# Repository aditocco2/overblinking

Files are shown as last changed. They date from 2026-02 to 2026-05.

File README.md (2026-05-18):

# Overblinking: The LED Matrix Graduation Cap

_lightslop taken to its logical extreme_

A DIY graduation cap project that shows a slideshow of pictures, GIFs, videos, and scrolling text messages on a 64x64 LED matrix.

Includes a high-performance LED matrix driver, a custom 3D printed mounting system, and a custom PCB.

thumb
staticmodetopdown
modesw

## Features
- Easy loading of data onto the SD card - no manual downscaling or image dumping needed
- SD card is exposed underneath the cap with a custom PCB, allowing easy replacement of cards
- Mode switch allows you to automatically switch to a less distracting "static mode" during speeches
- Whole system is powered through one battery pack
- Optional rain resistance using an acrylic sheet and 3D printed waterproofing shield
- Automatically initializes/recovers SD cards and survives card swaps
- Only required electronics skill for assembly is through-hole soldering
- Non-destructive design allows you to re-use components for other things post-ceremony (unlike the cap and gown themselves!)

## Build Your Own
For instructions on how to make your own LED matrix graduation cap, read the full guide [here](https://overblinking.substack.com)!

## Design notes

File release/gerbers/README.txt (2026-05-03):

Use control_board_2 if you have the Adafruit micro SD card breakout board.

Use control_board_2b if you could not get the Adafruit one and instead have the SparkFun one.

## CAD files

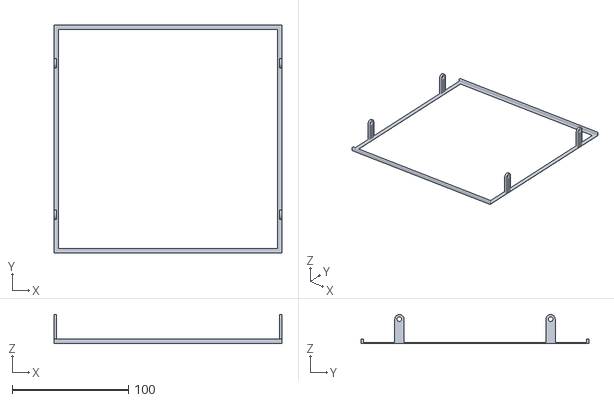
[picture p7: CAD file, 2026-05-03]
models/waterproofing_shield_2.stl
196.0 x 196.0 x 25.0

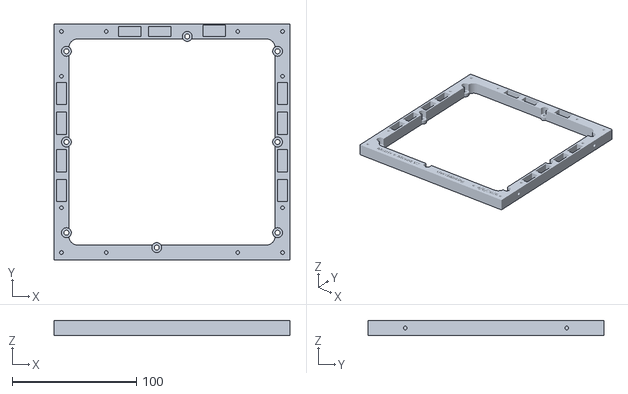
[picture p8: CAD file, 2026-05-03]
models/matrix_mount_2.stl
190.0 x 190.0 x 12.0

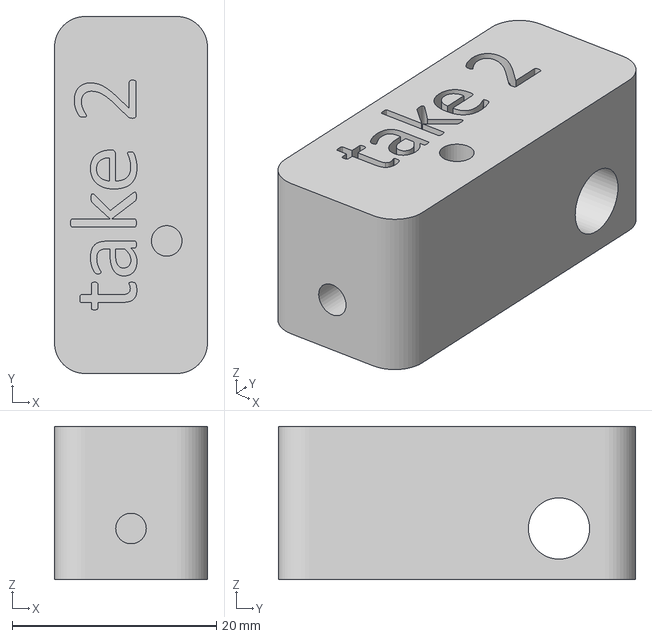
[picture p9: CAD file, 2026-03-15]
models/threadless_cube.3mf
15.0 x 35.0 x 15.0 mm

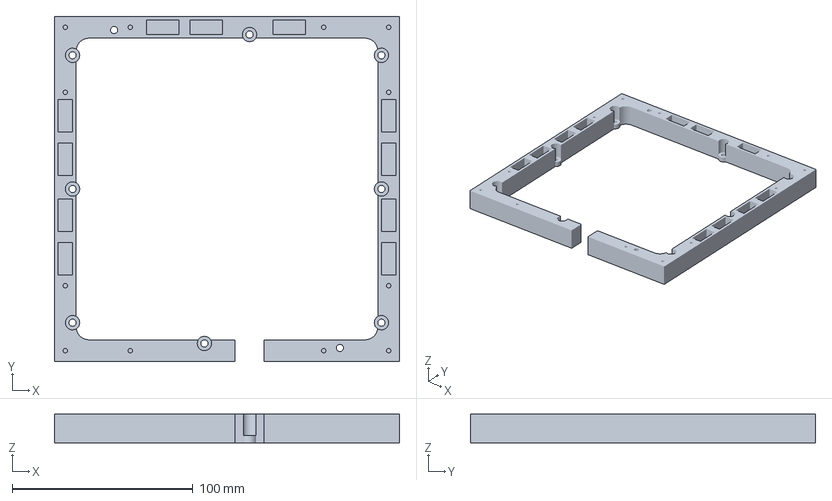
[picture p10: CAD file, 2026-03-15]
models/matrix_mount_1.3mf
191.0 x 191.0 x 16.0 mm

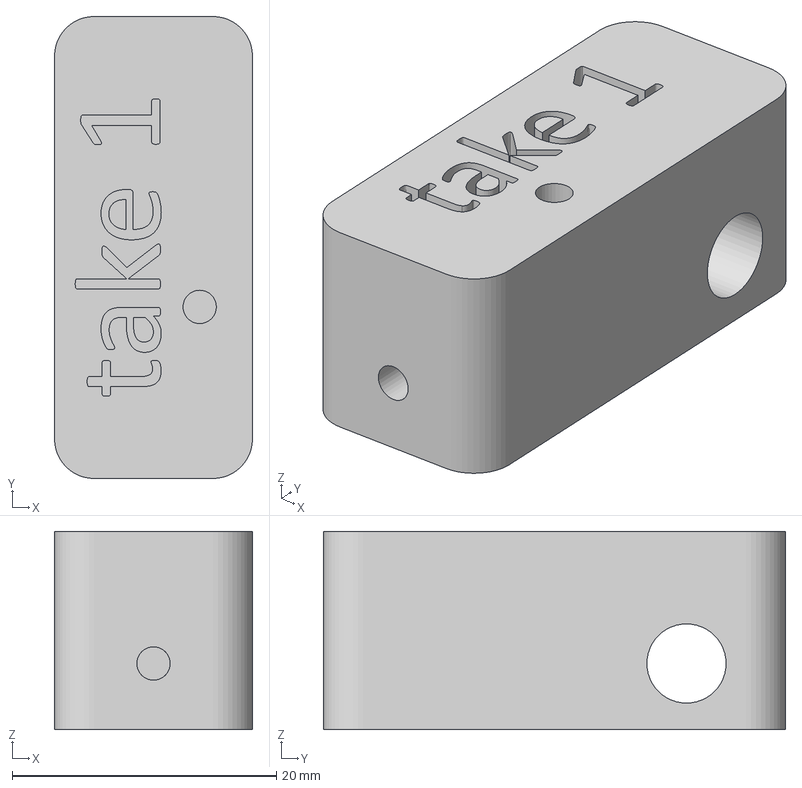
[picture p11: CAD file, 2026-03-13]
models/thread_cube.3mf
15.0 x 35.0 x 15.0 mm

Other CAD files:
release/models/waterproofing_shield_2.3mf
release/models/matrix_mount_2.3mf
models/matrix_mount_2.obj
models/thread_cube.stl
models/waterproofing_shield_2.obj
release/models/matrix_mount_2.obj
release/models/waterproofing_shield_2.obj

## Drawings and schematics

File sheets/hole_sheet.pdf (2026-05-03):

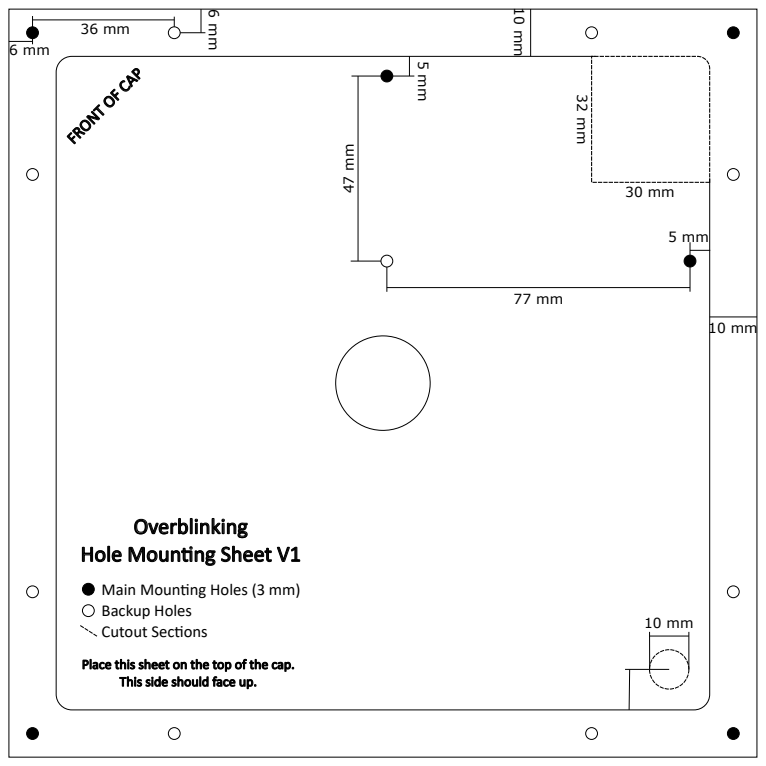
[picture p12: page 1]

FRONT OF CAP

Overblinking
Hole Mounng Sheet V1

Main Mounng Holes (3 mm)
Backup Holes
Cutout Secons

Place this sheet on the top of the cap.
This side should face up.

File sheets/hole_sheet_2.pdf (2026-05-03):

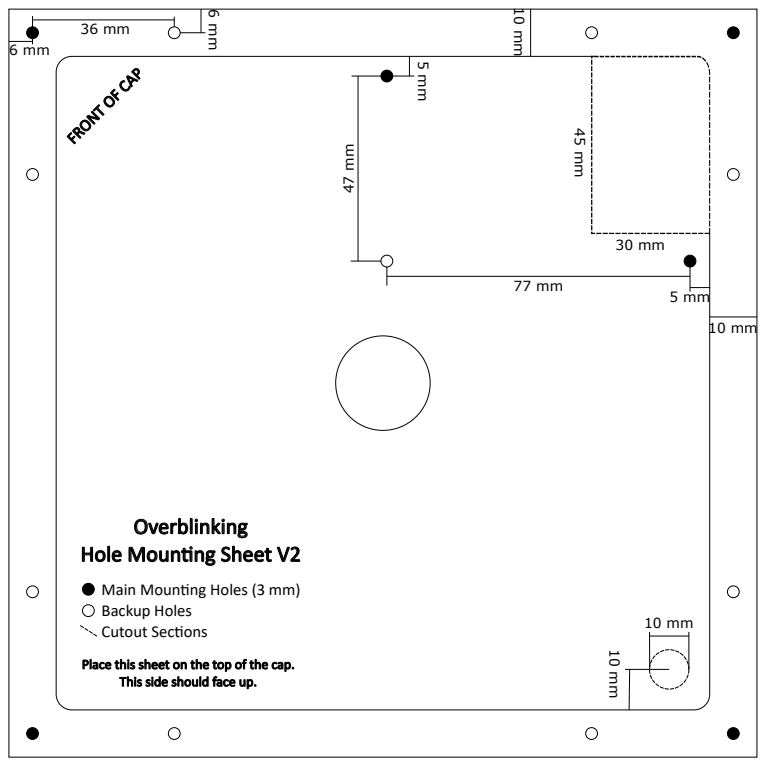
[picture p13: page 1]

FRONT OF CAP

Overblinking
Hole Mounng Sheet V2

Main Mounng Holes (3 mm)
Backup Holes
Cutout Secons

Place this sheet on the top of the cap.
This side should face up.

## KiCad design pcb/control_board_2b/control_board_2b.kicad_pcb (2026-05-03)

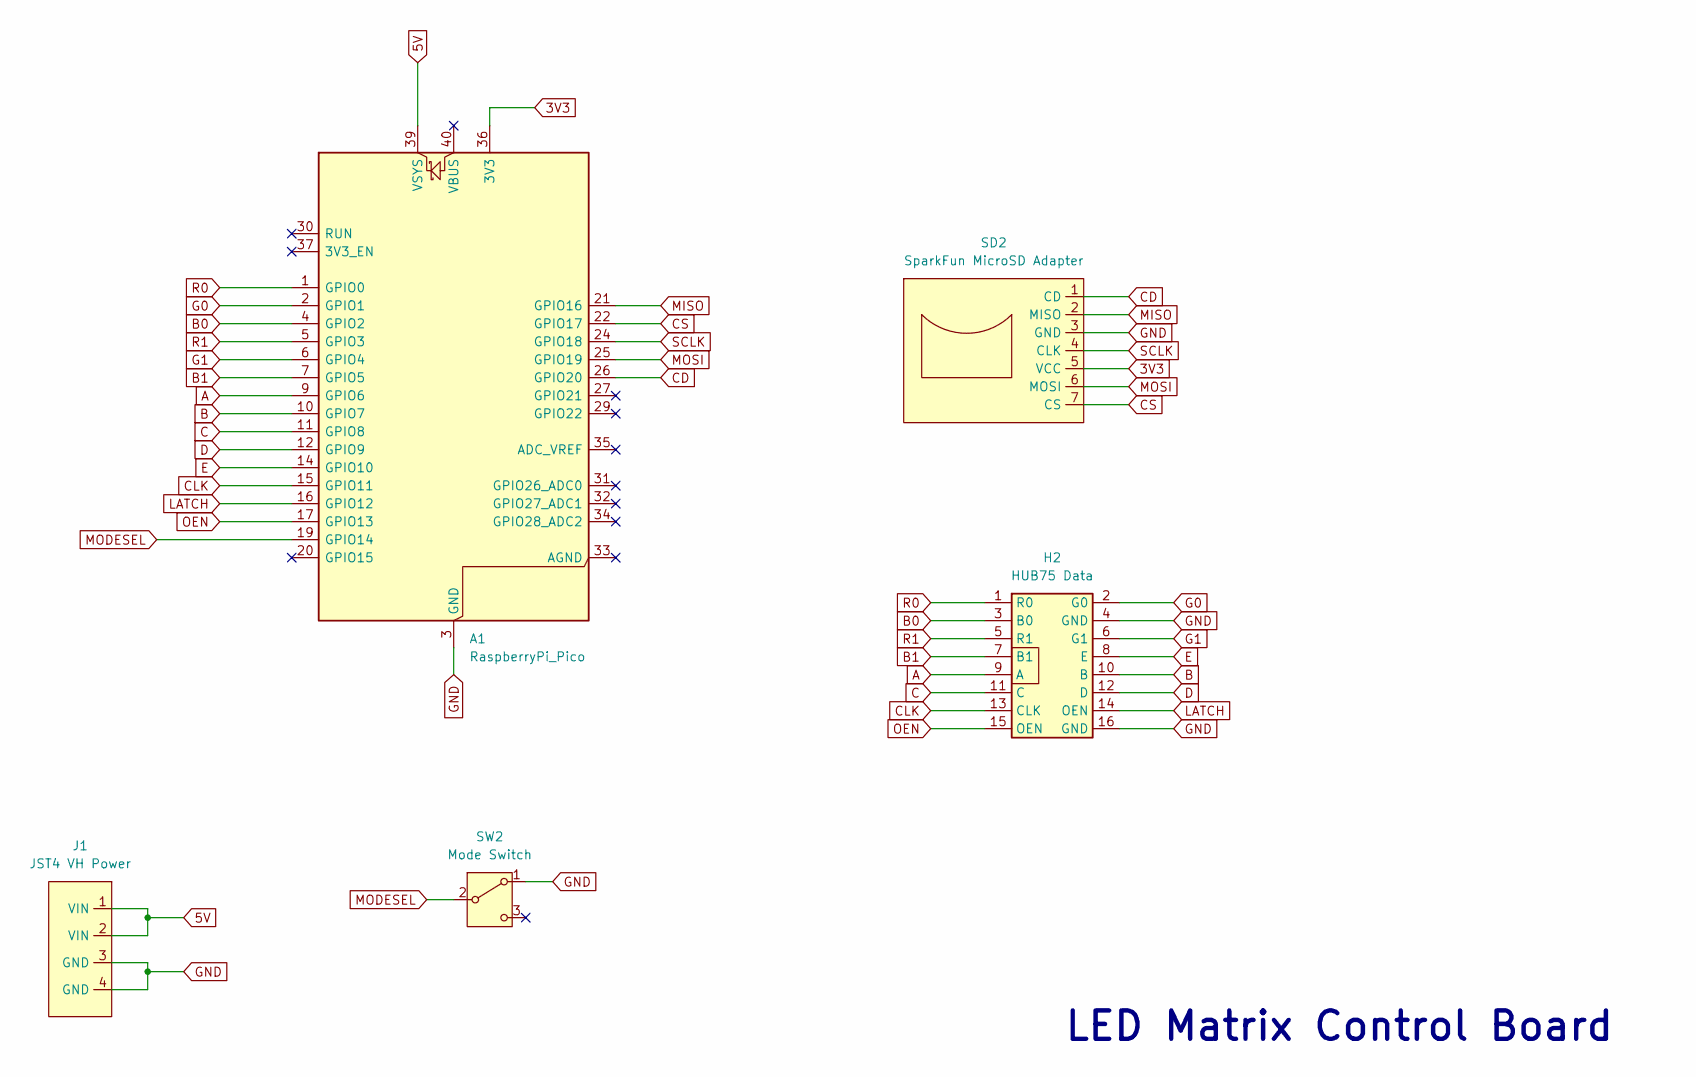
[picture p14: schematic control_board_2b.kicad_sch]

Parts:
A1: RaspberryPi_Pico; RaspberryPi_Pico_Common_Unspecified
H2: HUB75 Data; IDC-Header_2x08_P2.54mm_Vertical
J1: JST4 VH Power; JST_VH_B4PS-VH_1x04_P3.96mm_Horizontal
SD2: SparkFun MicroSD Adapter
SW2: Mode Switch; SW_Slide-03_Wuerth-WS-SLTV_10x2.5x6.4_P2.54mm

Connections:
3V3: A1.36 (3V3), SD2.5 (VCC)
5V: A1.39 (VSYS), J1.1 (VIN), J1.2 (VIN)
A: A1.9 (GPIO6), H2.9 (A)
B: A1.10 (GPIO7), H2.10 (B)
B0: A1.4 (GPIO2), H2.3 (B0)
B1: A1.7 (GPIO5), H2.7 (B1)
C: A1.11 (GPIO8), H2.11 (C)
CD: A1.26 (GPIO20), SD2.1 (CD)
CLK: A1.15 (GPIO11), H2.13 (CLK)
CS: A1.22 (GPIO17), SD2.7 (CS)
D: A1.12 (GPIO9), H2.12 (D)
E: A1.14 (GPIO10), H2.8 (E)
G0: A1.2 (GPIO1), H2.2 (G0)
G1: A1.6 (GPIO4), H2.6 (G1)
GND: A1.3 (GND), A1.8 (GND), A1.13 (GND), A1.18 (GND), A1.23 (GND), A1.28 (GND), A1.38 (GND), H2.4 (GND), H2.16 (GND), J1.3 (GND), J1.4 (GND), SD2.3 (GND), SW2.1 (A)
LATCH: A1.16 (GPIO12), H2.14 (OEN)
MISO: A1.21 (GPIO16), SD2.2 (MISO)
MODESEL: A1.19 (GPIO14), SW2.2 (B)
MOSI: A1.25 (GPIO19), SD2.6 (MOSI)
OEN: A1.17 (GPIO13), H2.15 (OEN)
R0: A1.1 (GPIO0), H2.1 (R0)
R1: A1.5 (GPIO3), H2.5 (R1)
SCLK: A1.24 (GPIO18), SD2.4 (CLK)

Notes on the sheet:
LED Matrix Control Board

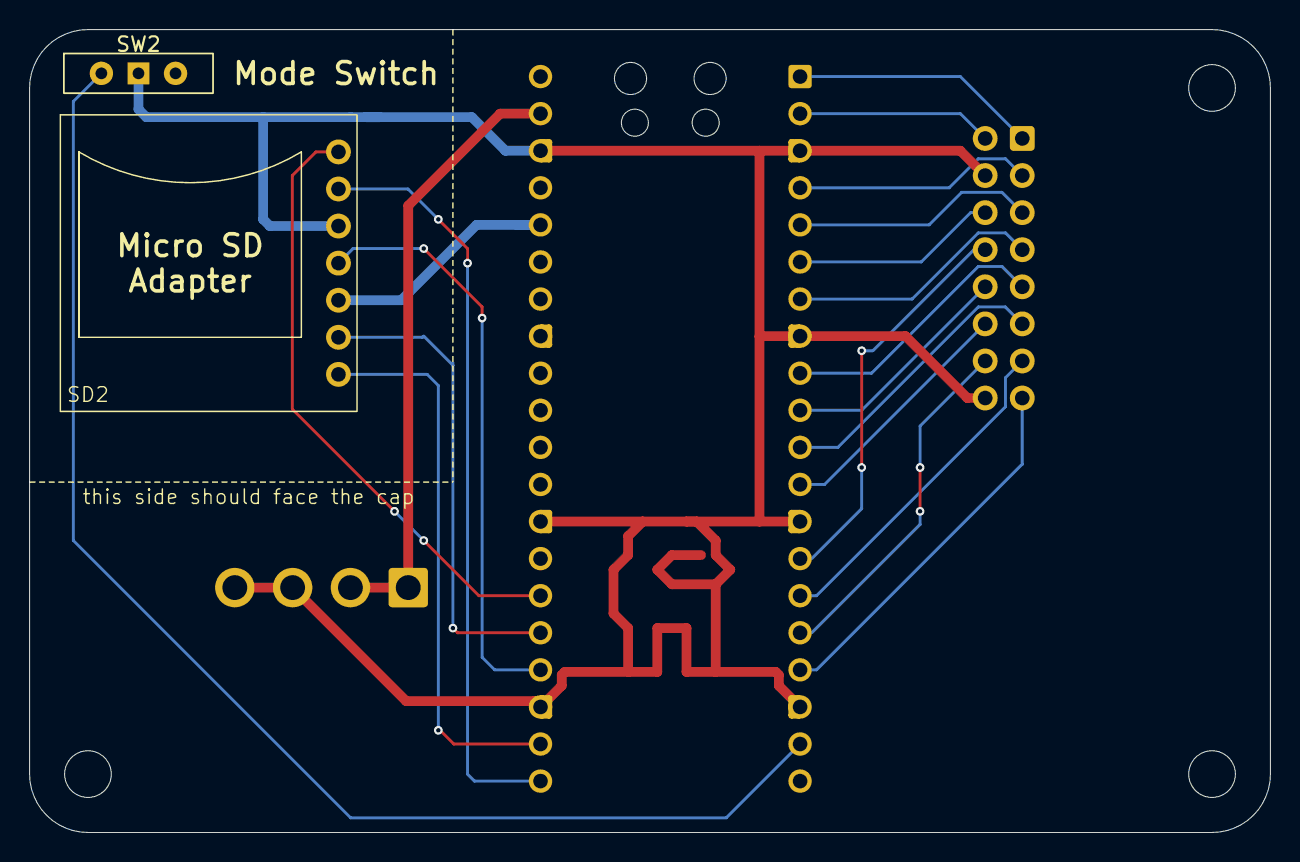
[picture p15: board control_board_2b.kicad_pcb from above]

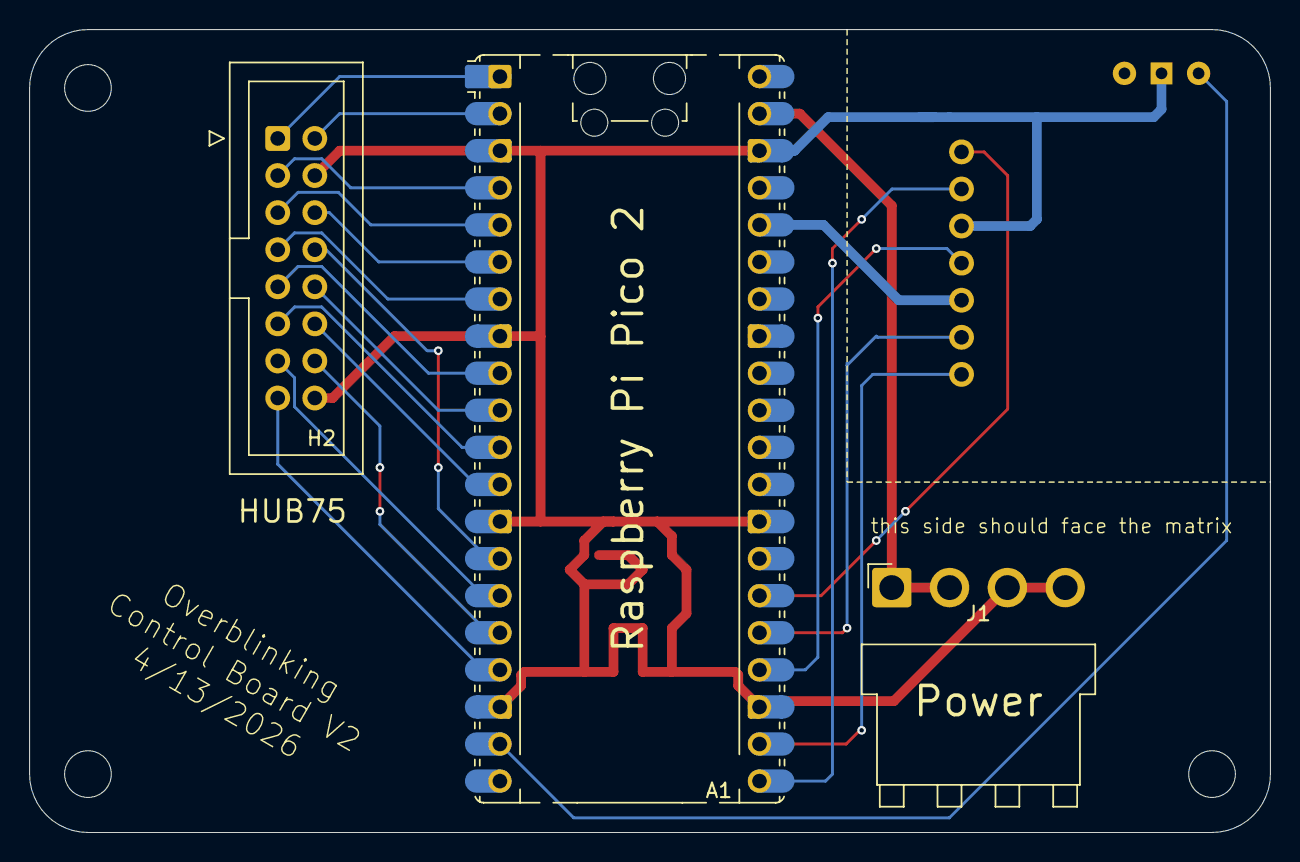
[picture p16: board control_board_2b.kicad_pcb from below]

Board: 2 copper layers, 85.0 x 55.0 mm, 5 parts (3 on the bottom side), 23 nets.

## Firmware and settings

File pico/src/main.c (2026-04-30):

// just one more state machine bro, that's all i need

#include <stdio.h>
#include <stdint.h>
#include <string.h>
#include "pico/stdlib.h"
#include "pico/rand.h"
#include "pico/time.h"

#include "sd_card.h"
#include "hub75.h"
#include "hub75_text.h"
#include "rgb565_colors.h"

#define MAX_MEDIA 146
#define TEXT_SCROLLING_PIXELS_PER_SECOND 40

#define TEXT_INST_SEPARATION 16

#define SECTORS_PER_FRAME (WIDTH * HEIGHT * 2 / BLOCK_SIZE)

#define NUM_MEDIA_INDEX 0
#define SWITCH_INTERVAL_INDEX 4
#define USE_STATIC_MODE_INDEX 6
#define RANDOMIZE_INDEX 7

#define TABLE_ROW_WIDTH 16

#define MEDIA_SECTOR_ADDR_INDEX 0
#define N_FRAMES_INDEX 4
#define FRAME_TIME_INDEX 8
#define MEDIA_TYPE_INDEX 15

#define MODESEL 14
#define STATIC_SWITCH_VALUE 0
#define SLIDESHOW_SWITCH_VALUE 1

typedef enum {TEXT, IMAGE, VIDEO} media_type_t;
typedef enum {STATIC, SLIDESHOW} mode_t;

typedef struct{
    uint16_t switch_interval_s;
    _Bool use_static_mode;
    _Bool randomize;

    mode_t current_mode;

    media_type_t current_media_type;
    uint32_t media_address;
    uint16_t frame_duration_ms;
    uint32_t current_media_index;
    uint32_t current_frame_num;
    uint32_t num_frames_in_video;
    uint32_t pool_size;
} player_data_t;

void main_fsm();

void slideshow_media_index_fsm(player_data_t *ts, _Bool reset);
_Bool player_get_metadata(player_data_t *ts, uint8_t *temp_buffer);
_Bool player_load_media(player_data_t *ts, uint8_t *temp_buffer);
_Bool player_get_frame(player_data_t *ts, uint8_t *frame_buffer);
_Bool text_scrolling_fsm(player_data_t *ts, char *str, _Bool reset);
uint16_t color_cycle_rgb565_fsm(_Bool reset);
_Bool mode_switched(player_data_t *ts);
void fill_array_sequentially(uint32_t *arr, uint32_t len);
void shuffle_array(uint32_t *arr, uint32_t len);

// Basic timer callbacks that just set flags
struct repeating_timer media_switch_timer, frame_switch_timer;
_Bool media_switch_flag, frame_switch_flag;
_Bool media_switch_cb(__unused repeating_timer_t *rt) {media_switch_flag = true;}
_Bool frame_switch_cb(__unused repeating_timer_t *rt) {frame_switch_flag = true;}

int main(){
    stdio_init_all();

    hub75_configure();
    hub75_set_brightness(10);

    gpio_init(MODESEL);
    gpio_pull_up(MODESEL);
    gpio_set_dir(MODESEL, GPIO_IN);

    while(67){
        main_fsm();
    }
}

void main_fsm(){
    static enum {INIT, GET_METADATA, SWITCH_MODE, LOAD_MEDIA, INITIALIZE_MEDIA, PLAY_MEDIA} state;

    static player_data_t ts;
    
    static _Bool sd_succ = true;

    uint8_t temp_buffer[BLOCK_SIZE];
    uint8_t *frame_buffer = (uint8_t *)hub75_get_back_buffer();

    if(!sd_succ){
        for(uint8_t x = 0; x < WIDTH; x++){
            for(uint8_t y = 0; y < HEIGHT; y++){
                hub75_set_pixel(x, y, 0);
            }
        }
        hub75_write_large_text("Insert", 32, 32, ALIGN_CENTER, ALIGN_BOTTOM, RGB565_Red);
        hub75_write_large_text("SD Card", 32, 32, ALIGN_CENTER, ALIGN_TOP, RGB565_Red);
        hub75_update();
        state = INIT;
    }

    switch(state){
        case INIT:
            sd_succ = sd_card_init();
            state = GET_METADATA;
            break;

        case GET_METADATA:
            sd_succ = player_get_metadata(&ts, temp_buffer);
            slideshow_media_index_fsm(&ts, true);
            state = SWITCH_MODE;
            break;

        case SWITCH_MODE:
            cancel_repeating_timer(&media_switch_timer);
            if(gpio_get(MODESEL) == STATIC_SWITCH_VALUE && ts.use_static_mode){
                ts.current_mode = STATIC;
            }
            else{
                ts.current_mode = SLIDESHOW;
                add_repeating_timer_ms(ts.switch_interval_s * 1000, media_switch_cb, NULL, 
                                       &media_switch_timer);
            }
            state = LOAD_MEDIA;
            break;

        case LOAD_MEDIA:
            if(ts.current_mode == STATIC){
                ts.current_media_index = ts.pool_size;
            }
            else{
                slideshow_media_index_fsm(&ts, false);
            }
            sd_succ = player_load_media(&ts, temp_buffer);

            state = INITIALIZE_MEDIA;
            break;
        
        case INITIALIZE_MEDIA:
            if (ts.current_media_type == VIDEO){
                sd_succ = player_get_frame(&ts, frame_buffer);
                hub75_update();
            }
            else if (ts.current_media_type == IMAGE){
                sd_succ = sd_card_read_blocks(ts.media_address, SECTORS_PER_FRAME, frame_buffer);
                hub75_update();
            }
            else if(ts.current_media_type == TEXT){
                sd_succ = text_scrolling_fsm(&ts, temp_buffer, true);
                hub75_update();
            }
            state = PLAY_MEDIA;
            break;

        case PLAY_MEDIA:
            if(media_switch_flag){
                media_switch_flag = false;
                state = LOAD_MEDIA;
            }
            else if(mode_switched(&ts)){
                state = SWITCH_MODE;
            }
            else if(frame_switch_flag && ts.current_media_type == VIDEO){
                frame_switch_flag = false;
                sd_succ = player_get_frame(&ts, frame_buffer);
                hub75_update();
            }
            else if(frame_switch_flag && ts.current_media_type == TEXT){
                frame_switch_flag = false;
                text_scrolling_fsm(&ts, temp_buffer, false);
                hub75_update();
            }
            else{
                sd_succ = sd_card_check_status();
            }
            break;
    }
}

_Bool player_get_metadata(player_data_t *ts, uint8_t *temp_buffer){
    if(!sd_card_read_block(0, temp_buffer, BLOCK_SIZE)){
        return false;
    }

    ts->switch_interval_s = *(uint16_t *)&temp_buffer[SWITCH_INTERVAL_INDEX];
    ts->use_static_mode = *(_Bool *)&temp_buffer[USE_STATIC_MODE_INDEX];
    ts->randomize = *(_Bool *)&temp_buffer[RANDOMIZE_INDEX];

    ts->pool_size = *(uint32_t *)&temp_buffer[NUM_MEDIA_INDEX];
    if(ts->use_static_mode){
        ts->pool_size = ts->pool_size - 1;
    }

    return true;
}

void slideshow_media_index_fsm(player_data_t *ts, _Bool reset){
    static enum {INIT, SHUFFLE, TRAVERSE} state;

    static uint32_t media_index_array[MAX_MEDIA];
    static uint32_t tag = 0;

    if(reset){
        state = INIT;
    }

    switch(state){
        case INIT:
            fill_array_sequentially(media_index_array, ts->pool_size);
            tag = 0;
            if(ts->randomize){
                state = SHUFFLE;
            }
            else{
                state = TRAVERSE;
            }
            break;
        case SHUFFLE:
            shuffle_array(media_index_array, ts->pool_size);
            tag = 0;
            state = TRAVERSE;
            break;
        case TRAVERSE:
            tag++;
            if(ts->randomize && tag >= ts->pool_size - 1){
                state = SHUFFLE;
            }
            else if(tag >= ts->pool_size){
                tag = 0;
            }
            break;
    }

    ts->current_media_index = media_index_array[tag];
}

_Bool player_load_media(player_data_t *ts, uint8_t *temp_buffer){
    
    cancel_repeating_timer(&frame_switch_timer);

    uint32_t table_row = ts->current_media_index + 1;
    uint16_t sector = table_row / (BLOCK_SIZE / TABLE_ROW_WIDTH);
    uint16_t table_row_index = table_row * TABLE_ROW_WIDTH % BLOCK_SIZE;

    if(!sd_card_read_block(sector, temp_buffer, BLOCK_SIZE)){
        return false;
    }

    ts->media_address = *(uint32_t *)&temp_buffer[table_row_index + MEDIA_SECTOR_ADDR_INDEX];

    char media_type_char = *(char *)&temp_buffer[table_row_index + MEDIA_TYPE_INDEX];
    switch(media_type_char){
        case 'i':
            ts->current_media_type = IMAGE;
            break;
        case 'v':
            ts->current_media_type = VIDEO;
            ts->num_frames_in_video = *(uint32_t *)&temp_buffer[table_row_index + N_FRAMES_INDEX];
            ts->frame_duration_ms = *(uint16_t *)&temp_buffer[table_row_index + FRAME_TIME_INDEX];
            ts->current_frame_num = 0;
            add_repeating_timer_ms(ts->frame_duration_ms, frame_switch_cb, NULL, 
                                   &frame_switch_timer);
            break;
        case 't':
            ts->current_media_type = TEXT;
            add_repeating_timer_ms(1000 / TEXT_SCROLLING_PIXELS_PER_SECOND, frame_switch_cb, NULL, 
                                   &frame_switch_timer);
            break;
    }

    return true;
}

_Bool player_get_frame(player_data_t *ts, uint8_t *frame_buffer){
    if(!sd_card_read_blocks(ts->media_address + (ts->current_frame_num * SECTORS_PER_FRAME), 
                            SECTORS_PER_FRAME, frame_buffer)){
        return false;
    }

    ts->current_frame_num = ts->current_frame_num + 1;
    if(ts->current_frame_num == ts->num_frames_in_video){
        ts->current_frame_num = 0;
    }

    return true;
}

_Bool text_scrolling_fsm(player_data_t *ts, char *str, _Bool reset){
    static enum {INIT, SCROLL} state;

    static uint16_t color;
    static int16_t start_x;
    int16_t current_x;
    static uint16_t len;

    if(reset){
        state = INIT;
    }

    switch(state){
        case INIT:
            start_x = WIDTH;

            if(!sd_card_read_block(ts->media_address, str, BLOCK_SIZE)){
                return false;
            }

            len = strlen(str);

            state = SCROLL;
            break;
            
        case SCROLL:
            // set screen black
            for(uint8_t x = 0; x < WIDTH; x++){
                for(uint8_t y = 0; y < HEIGHT; y++){
                    hub75_set_pixel(x, y, 0);
                }
            }
            
            color = color_cycle_rgb565_fsm(false);

            start_x--;
            current_x = start_x;

            do{
                hub75_write_medium_text(str, current_x, HEIGHT/2, ALIGN_LEFT, ALIGN_CENTER, color);
                current_x += len * MEDIUM_FONT_WIDTH + TEXT_INST_SEPARATION;
            }while(current_x < WIDTH);

            break;
    }

    return true;
}

uint16_t color_cycle_rgb565_fsm(_Bool reset){

    static enum {INCREASE_G, DECREASE_R, INCREASE_B, DECREASE_G, INCREASE_R, DECREASE_B} state;

    // we are using rgb555 for simplicity here, will convert to rgb565 on the way out
    static uint8_t r = 31;
    static uint8_t g = 0;
    static uint8_t b = 0;

    if(reset){
        state = INCREASE_G;
        r = 31;
        g = 0;
        b = 0;
    }

    switch(state){
        case INCREASE_G:
            g++;
            if(g == 31){
                state = DECREASE_R;
            }
            break;
            
        case DECREASE_R:
            r--;
            if(r == 0){
                state = INCREASE_B;
            }
            break;

        case INCREASE_B:
            b++;
            if(b == 31){
                state = DECREASE_G;
            }
            break;
        
        case DECREASE_G:
            g--;
            if(g == 0){
                state = INCREASE_R;
            }
            break;

        case INCREASE_R:
            r++;
            if(r == 31){
                state = DECREASE_B;
            }
            break;

        case DECREASE_B:
            b--;
            if(b == 0){
                state = INCREASE_G;
            }
            break;   
    }

    // build the rgb565 pixel by shifting the green pixel 1 up
    uint16_t pix = (r << 11) | (g << 6) | (b << 0);
    return pix;
}

_Bool mode_switched(player_data_t *ts){
    if(ts->use_static_mode == false){
        return false;
    }
    else if(ts->current_mode == STATIC && gpio_get(MODESEL) == SLIDESHOW_SWITCH_VALUE){
        return true;
    }
    else if(ts->current_mode == SLIDESHOW && gpio_get(MODESEL) == STATIC_SWITCH_VALUE){
        return true;
    }
    else{
        return false;
    }
}

void fill_array_sequentially(uint32_t *arr, uint32_t len){
    for(uint32_t i = 0; i < len; i++){
        arr[i] = i;
    }
}

void shuffle_array(uint32_t *arr, uint32_t len){
    for(uint32_t i = len - 1; i > 0; i--){
        uint32_t j = get_rand_32() % (i + 1);

        uint32_t temp = arr[j];
        arr[j] = arr[i];
        arr[i] = temp;
    }
}

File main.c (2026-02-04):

#include "FreeRTOS.h"
#include "task.h"
#include "FreeRTOSConfig.h"
#include <pico/stdlib.h>
#include <stdio.h>
#include "hub75.h"
#include "ecd1015.h"

#define BUTTON_PIN 15

#define HUB75_STACK_SIZE 20000
#define BUTTON_STACK_SIZE 128

static bool hub75_on = true;

void hub75_task(__unused void *params);
void button_task(__unused void *params);

StaticTask_t hub75_tcb;
StackType_t hub75_stack[HUB75_STACK_SIZE];
StaticTask_t button_tcb;
StackType_t button_stack[BUTTON_STACK_SIZE];

void main(void){
    stdio_init_all();

    xTaskCreateStatic(hub75_task, "HUB75Thread", HUB75_STACK_SIZE, NULL, 1, hub75_stack, &hub75_tcb);
    xTaskCreateStatic(button_task, "ButtonThread", BUTTON_STACK_SIZE, NULL, 1, button_stack, &button_tcb);

    vTaskStartScheduler();
}

void hub75_task(__unused void *params){
    hub75_configure();
    hub75_load_image((uint16_t*)ecd1015);

    while(1){
        if(hub75_on){
            hub75_refresh();
        }
        taskYIELD();
    }
}

void button_task(__unused void *params){
    static bool current_state = false, previous_state = false;

    gpio_init(BUTTON_PIN);
    gpio_pull_up(BUTTON_PIN);
    gpio_set_dir(BUTTON_PIN, GPIO_IN);
    
    while(1){
        previous_state = current_state;
        current_state = !gpio_get(BUTTON_PIN);
    
        if(current_state && !previous_state){
            hub75_on = !hub75_on;
        }

        vTaskDelay(pdMS_TO_TICKS(5));
    }

}

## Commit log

2026-02-12 improved the sd card driver somewhat
    oaeugh
2026-02-17 dangerously approaching the DMA rabbit hole
2026-02-23 Working on new CPU-less HUB75 driver
2026-02-24 1000 HZ HUB75 DRIVER IN PROGRESS
    disclaimer: it's 1000 Hz on low brightness. refresh rate depends on the pulse width.
2026-02-27 Non-blocking player with proper SD recovery and a text driver. Ws all around
2026-03-13 added first few 3d models
    [thread_cube.3mf, thread_cube.stl]
2026-03-13 Cleaned up the text driver (?) and made medium fonts
2026-03-15 finished matrix mount v1
    [matrix_mount_1.3mf, threadless_cube.3mf]
2026-03-21 some schematic changes
    [control_board_1.kicad_pcb, control_board_1.kicad_sch]
2026-04-11 matrix mount 2 and pcb
    [matrix_mount_2.3mf]
2026-04-18 He was forced to pay $40 PCB shipping AGAIN
    [control_board_2-B_Cu.gbr, control_board_2-B_Mask.gbr, control_board_2-B_Paste.gbr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]
2026-04-25 made mounting sheet pdf
2026-04-27 improved main code
    recoupled main/player FSMs for less confusion, got improved shuffle working,
    changed mode switch logic to prepare for slide switch instead of button
2026-05-03 organized & made first release
    [control_board_2b-B_Cu.gbr, control_board_2b-B_Mask.gbr, control_board_2b-B_Paste.gbr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]
